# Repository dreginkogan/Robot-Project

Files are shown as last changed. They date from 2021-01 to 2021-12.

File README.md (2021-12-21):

# Robot-Project

Just a robot that drives around I guess

<p align="center">
  
</p>

<p align="center">
  
</p>

------------------
videos:
https://www.youtube.com/watch?v=NOP5lisCpfA&list=PLNNotAlA-lrEumtGw5MK10c69R9y6Rw0v&index=7

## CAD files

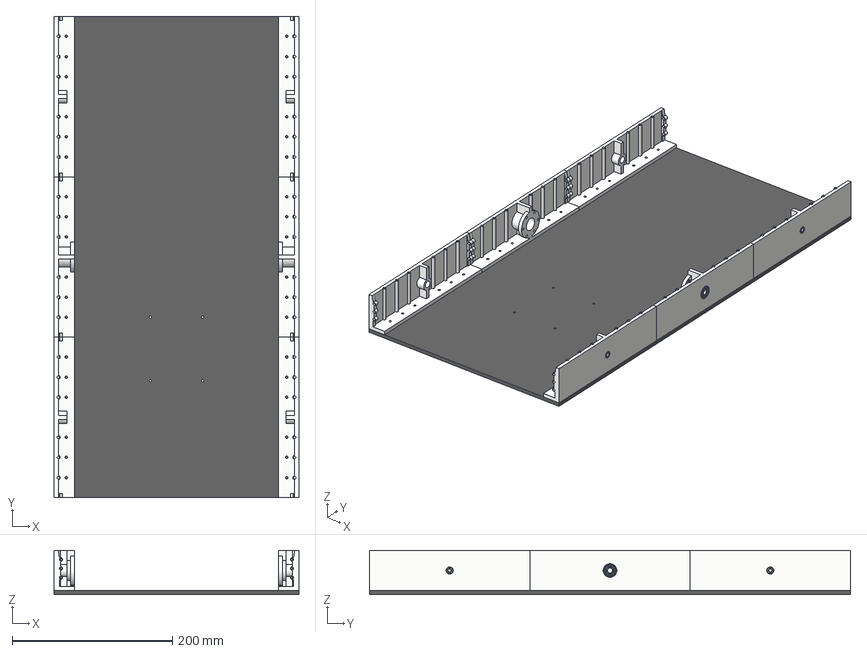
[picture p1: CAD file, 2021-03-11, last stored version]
CAD/body/Body assembly v19.step
305.0 x 600.0 x 55.0 mm
INNER_RING x 4
OUTER_RING x 4
BEARING_BALL x 4
SHEILD x 8
METAL_CAGE x 4
Middle x 2
Bellypan
Ends x 4
4mm bore bearing x 8

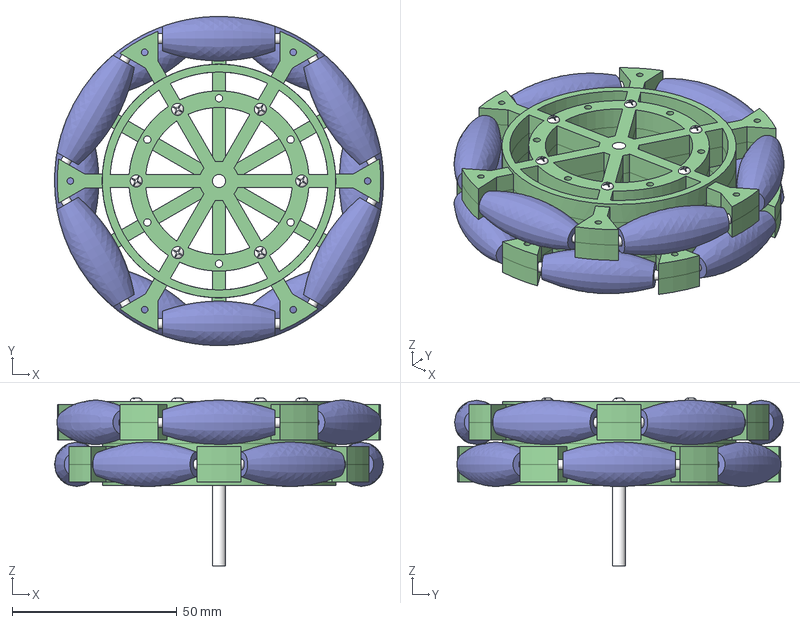
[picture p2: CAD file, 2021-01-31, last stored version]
CAD/wheels/Omniwheel Assembly v11.step
99.9 x 100.0 x 51.0 mm
Omni rod x 12
Omniwheel spoke x 4
Wheel Roller x 12
Omni Axle
2mm screw 10mm x 6

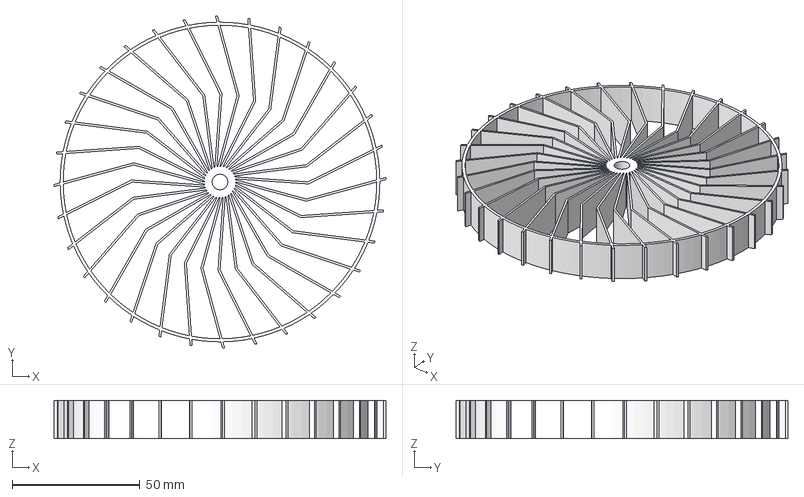
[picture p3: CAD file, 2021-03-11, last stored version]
CAD/wheels/Motor Wheel 2.0 v2.step
129.8 x 129.8 x 15.0 mm

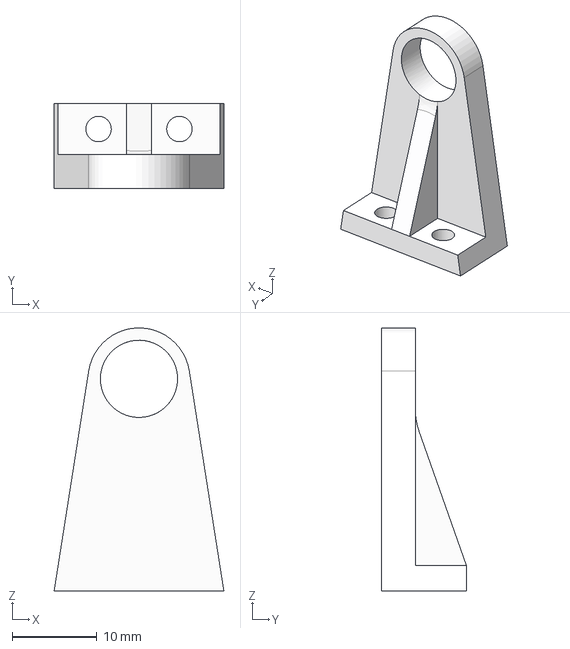
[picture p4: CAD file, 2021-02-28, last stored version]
CAD/wheels/End wheel stabilizer v4.step
20.0 x 10.0 x 31.0 mm

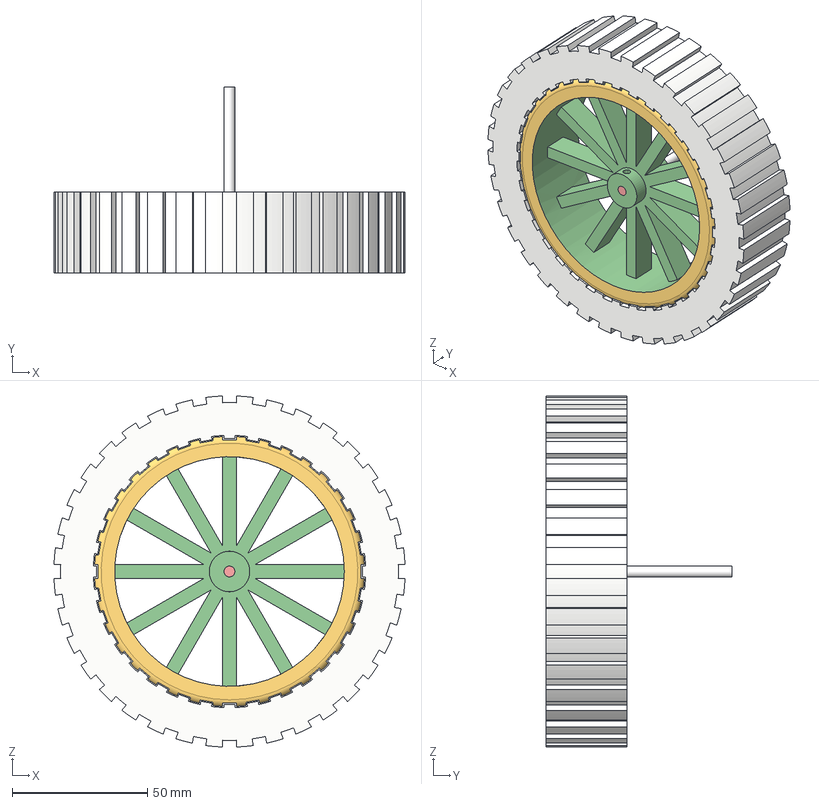
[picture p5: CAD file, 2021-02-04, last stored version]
CAD/wheels/End wheels v5.step
129.9 x 69.0 x 129.9 mm
Motorwheel extension
End axle

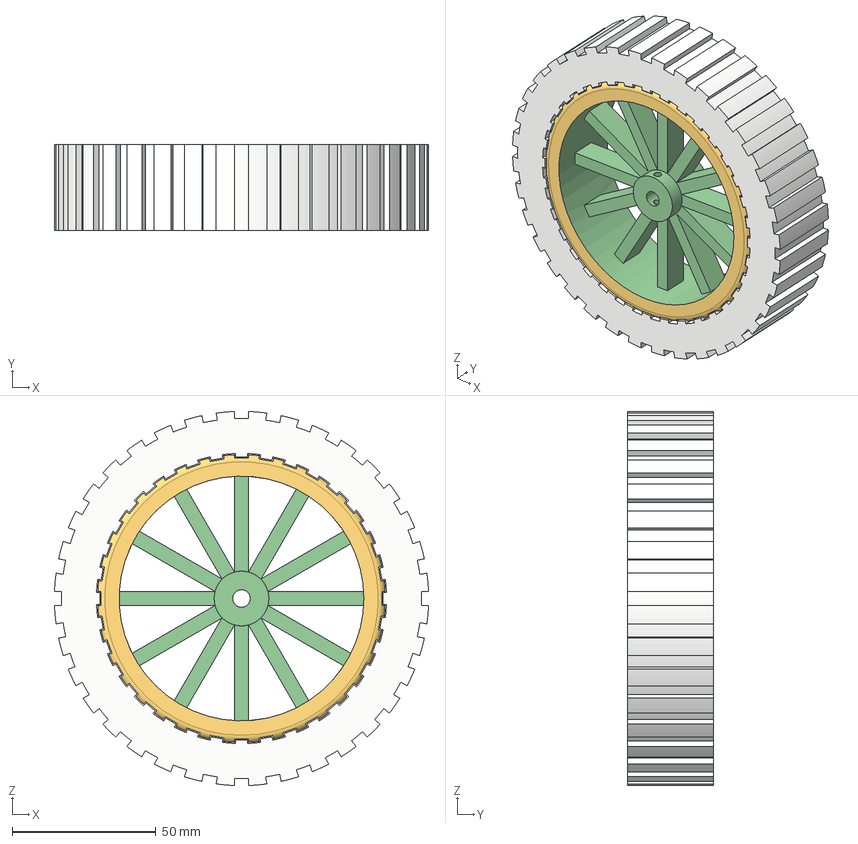
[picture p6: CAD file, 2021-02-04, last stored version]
CAD/wheels/Motorwheel v8.step
129.9 x 30.0 x 129.9 mm
Motorwheel extension

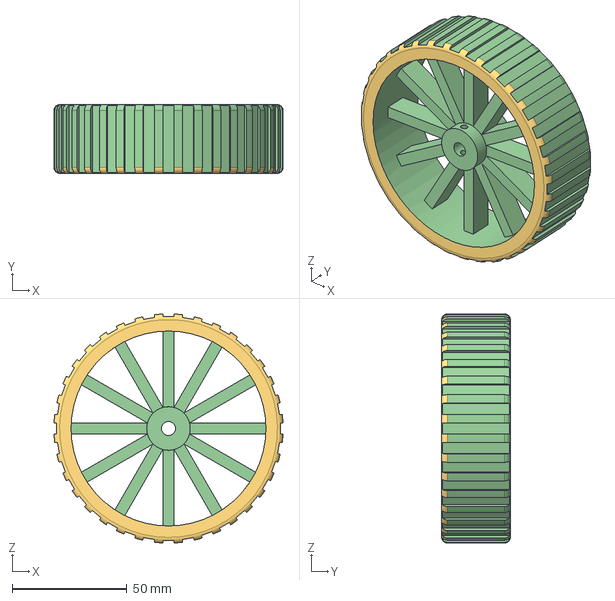
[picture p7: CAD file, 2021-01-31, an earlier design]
CAD/wheels/Motorwheel v7.step
99.9 x 30.0 x 99.9 mm

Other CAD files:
CAD/wheels/End Wheel 2.0 v1.step

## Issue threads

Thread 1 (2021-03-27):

Test 1 conclusions

dreginkogan, 2021-03-27:
SLA Batteries are *way* too heavy. Lithium-ion batteries seem like a better option now.

The DC motors on the robot do not give enough torque. This can be fixed with more gears, but, metal gearboxes now seem like a better idea, as mounting plastic gears to steel rods efficiently is basically impossible without a drill press, which I don't have. Also, a metal gearbox can save me space, allowing for more modifications to the robot.

The current wheel design is at-most ok on flat, hard, ground. They are too stiff, and have low friction. It is better to design larger wheels, make them yield to pressure better, and possibly coat them in a high-friction material. Also, if the elevation on each side of the robot is different, one wheel will spin without actually making the robot move.

The robot will still move because of breaking, as the friction isn't enough to completely counteract the robot's momentum, which is even larger with the heavy battery.

Future changes:
-Metal gearbox with better motor, to provide higher torque
-Wheels that yield to pressure better and provide more friction
-Lighter battery

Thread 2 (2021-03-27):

4 wheels instead of 6, thicker wheels, and belt-based motor reduction, voronoi patterns, and lithium ion batteries

dreginkogan, 2021-03-27:
4 wheels seems like a better idea for a robot meant to be driven outside. Treads also would have been effective, but that is currently outside of my skill level, so I will return to that later.

Wheels will now be 30mm thick instead of 15. This is due to the fact that with more of the wheel being in contact with the ground, traction will be better.

Batteries will be changed to lithium ion, because they are much lighter and smaller than SLA batteries.

Voronoi patterns will be added to some parts of the robot as they help reduce material used, and just look nice. Clear plastic from recycled plastic containers will be needed to cover them, to prevent dirt, grass, etc from getting inside the robot.

Robot will overall be smaller, in order to use the space more effectively

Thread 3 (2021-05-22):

Current state of robot 5/21

dreginkogan, 2021-05-22:
The voronoi stuff was cool, but was discarded because it would allow dirt to get inside, and covering the holes with clear material would be annoying to do.

Walls are now thicker to make them less wobbly, and to accommodate a top part on the robot better.

I may be running out of pins on my Arduino, and can't accommodate all sensors and motor controllers.

Motors were also changed to some $15 200 rpm gearboxes I found on amazon. This saved a LOT of internal space, so i can fit more electronics, batteries, etc. Also, each wheel has its own motor now.

===============================================
Future changes

New battery
Second arduino

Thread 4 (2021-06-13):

Current state of robot 6/13

dreginkogan, 2021-06-13:
Robot now has NiMh batteries which is many times lighter than the SLA batteries.

Two Arduino unos are used: one for sensors and one for motors.

The biggest current issue is with the wheels. The wheels are very weakly connected to the motors and fall off sometimes. They are also not big enough for driving through grass.

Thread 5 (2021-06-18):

Current state of robot 6/18

dreginkogan, 2021-06-18:
The wheels are now bigger and can drive through grass better, but the motors are too low torque to move the robot effectively. The robot also can't turn because of the low torque.

Additionally, I made the wiring much cleaner, so I can actually see what's going on inside the robot.

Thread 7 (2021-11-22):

Motors have too low of a torque

dreginkogan, 2021-11-22:
As a result of low torque, the robot can only move forwards and backwards. The wheels do not provide sufficient torque for the robot to be able to turn.

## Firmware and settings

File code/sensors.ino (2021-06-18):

#include <Wire.h>


#define trigPin 11
#define echoPin 10

#define trigPinL 9
#define echoPinL 6

#define trigPinR 5
#define echoPinR 3

float duration, distance, durationL, distanceL, durationR, distanceR;
bool light;

#define led 7

void setup() {
  // put your setup code here, to run once:

  pinMode(trigPin, OUTPUT); 
  pinMode(echoPin, INPUT); 

  pinMode(trigPinL, OUTPUT); 
  pinMode(echoPinL, INPUT); 

  pinMode(trigPinR, OUTPUT); 
  pinMode(echoPinR, INPUT); 


  pinMode(led, OUTPUT);
  Serial.begin(9600);

  // Start the I2C Bus as Master
  Wire.begin(); 

}

void loop() {
  
  measureDistL();
  Serial.print(distanceL);

  Serial.print(" | ");

  measureDist();
  Serial.print(distance);

  Serial.print(" | ");

  measureDistR();
  Serial.println(distanceR);

  if (distanceL < 150 && distance < 100 && distanceR < 150) {
    light = true;
  } else {
    light = false;
  }

  Wire.beginTransmission(9); // transmit to device #9
  Wire.write(light);              // sends x 
  Wire.endTransmission();    // stop transmitting
}

void measureDist() {

  digitalWrite(trigPin, LOW); 

  delayMicroseconds(2); 

  digitalWrite(trigPin, HIGH); 

  delayMicroseconds(10); 

  digitalWrite(trigPin, LOW);

  duration = pulseIn(echoPin, HIGH); 
  distance = (duration*.0343)/2; //duration.0343
}

void measureDistL() {

  digitalWrite(trigPinL, LOW); 

  delayMicroseconds(2); 

  digitalWrite(trigPinL, HIGH);

  delayMicroseconds(10); 

  digitalWrite(trigPinL, LOW);

  durationL = pulseIn(echoPinL, HIGH); 
  distanceL = (durationL*.0343)/2; //duration.0343

}

void measureDistR() {

  digitalWrite(trigPinR, LOW); 

  delayMicroseconds(2); 

  digitalWrite(trigPinR, HIGH);

  delayMicroseconds(10); 

  digitalWrite(trigPinR, LOW);

  durationR = pulseIn(echoPinR, HIGH); 
  distanceR = (durationR*.0343)/2; //duration.0343

}

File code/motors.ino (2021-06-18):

#include <Wire.h>

#define in1L 2
#define in2L 4
#define enAL 5
#define enBL 6
#define in3L 7
#define in4L 8

#define in1R 0
#define in2R 1
#define enAR 11
#define enBR 9
#define in3R 10
#define in4R 3


//#define LED = 13


int LED = 13;
bool x = false;

int speed = 255;

void setup() {
  pinMode(in1L, OUTPUT);
  pinMode(in2L, OUTPUT);
  pinMode(enAL, OUTPUT);
  pinMode(in3L, OUTPUT);
  pinMode(in4L, OUTPUT);
  pinMode(enBL, OUTPUT);

  pinMode(in1R, OUTPUT);
  pinMode(in2R, OUTPUT);
  pinMode(enAR, OUTPUT);
  pinMode(in3R, OUTPUT);
  pinMode(in4R, OUTPUT);
  pinMode(enBR, OUTPUT);

  // Define the LED pin as Output
  pinMode (LED, OUTPUT);
  // Start the I2C Bus as Slave on address 9
  Wire.begin(9); 
  // Attach a function to trigger when something is received.
  Wire.onReceive(receiveEvent);
}
void receiveEvent(int bytes) {
  x = Wire.read();    // read one character from the I2C
}
void loop() {

  analogWrite(enAL, speed);
  analogWrite(enBL, speed);

  analogWrite(enAR, speed);
  analogWrite(enBR, speed);
  
  if (x == true) {
    digitalWrite(LED, HIGH);
    stop();
  } else {
    digitalWrite(LED, LOW);
    forward();
  }

}

void forward() {
  digitalWrite(in1L, LOW); //back left
  digitalWrite(in2L, HIGH);

  digitalWrite(in3L, HIGH); //front left
  digitalWrite(in4L, LOW);

  digitalWrite(in1R, HIGH); //back right
  digitalWrite(in2R, LOW);

  digitalWrite(in3R, LOW); //front right
  digitalWrite(in4R, HIGH);
}

void stop() {
  digitalWrite(in1L, LOW);
  digitalWrite(in2L, LOW);
  digitalWrite(in3L, LOW);
  digitalWrite(in4L, LOW);

  digitalWrite(in1R, LOW);
  digitalWrite(in2R, LOW);
  digitalWrite(in3R, LOW);
  digitalWrite(in4R, LOW);
}

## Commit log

2021-01-19 Create Gearbox assembly v10.step
2021-01-31 Create Motorwheel v7.step
    [Motorwheel v7.step]
2021-01-31 Create Omniwheel Assembly v11.step
    [Omniwheel Assembly v11.step]
2021-02-04 Create Motorwheel v8.step
    [Motorwheel v8.step]
2021-02-04 Create End wheels v5.step
    [End wheels v5.step]
2021-02-04 Create Sensor assembly v5.step
2021-02-28 Create End wheel stabilizer v4.step
    [End wheel stabilizer v4.step]
2021-03-11 Create End Wheel 2.0 v1.step
    [End Wheel 2.0 v1.step]
2021-03-11 Create Motor Wheel 2.0 v2.step
    [Motor Wheel 2.0 v2.step]
2021-03-11 Create Body assembly v19.step
    [Body assembly v19.step]
2021-03-11 Create arduino uno v1.step
